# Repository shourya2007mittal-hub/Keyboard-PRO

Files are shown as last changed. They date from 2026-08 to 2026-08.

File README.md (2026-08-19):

# Keyboard-PRO



I have building a 65% layout keyboard and it is  based on Seed Studio Xiao nrf52840 because it has Bluetooth capabilities. the number of available pins on Xiao was less So I used 2 expanders for connection . <br>The keyboard also has a  3.7v battery for the power also it could be charged by the USB-C available on xiao as it has an inbuilt charging IC. <br> The keyboard also has an 0.91 inch OLED Screen . Which will be used to display present time/ and how long are you working for . <br> The  Switches  on the board are also hot swappable. So there is no need to solder the switches and we could easily change it .    <br> The board also include a micro pad of 4x3 layout which could be used as shot-cuts for any apps  and has 3 rotor encoders to control volume/Brightness/ timeline (while editing/ Zoom in-out).

<br> The CAD design is a three layered design in which the Bottom layer holds the keyboard PCB and there is a middle layer holds and give structure to the Switches and stabilizes them . then the top layer close and finished the board. All the three pieces connect to each other in a leg-joint manner. 
<br>

## Features
-  nrf52840 Rp2040
- uses 65% Keyboard Layout 
-  Uses Keyboard Matrix
-  Had a rotor encoder and an 0.91 inch oled screen
-  had a 4x3 layout MicroPad

  | Item | Price | Source |
| :--- | :---: | :--- |
| PCB + Shipping - Coupons | 28.74 | JLCPCB |
| KeyCaps | 15.04 | [Meckeys Link](https://meckeys.com/shop/accessories/keyboard-accessories/keycaps/gengar-anime-keycap-set/) |
| Hot-swap (pack of 10) x7 | 5.20 | [Meckeys Link](https://meckeys.com/shop/accessories/keyboard-accessories/key-switches/kailh-hot-swap-socket/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) |
| Switches (pack of 10) x 8 | 25.20 | [Meckeys Link](https://meckeys.com/shop/accessories/keyboard-accessories/key-switches/hmx-xinhai-switch/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) |
| Stabilizers | 10.76 | [Meckeys Link](https://meckeys.com/shop/accessories/keyboard-accessories/more/glorious-goat-stabilizers/) |
| Meckey shipping | 1.10 | meckeys.com |
| Expander x 2 | 6.22 | [Robu Link](https://robu.in/product/pca9555dwr-texas-instruments-400khz-soic-24-300mil-i-o-expanders-rohs/) |
| XIAO BLE nRF52840 | 12.40 | [Robu Link](https://robu.in/product/seeed-studio-xiao-ble-nrf52840/) |
| 0.91 OLED | 1.93 | [Robu Link](https://robu.in/product/blue-oled-display-module/) |
| Rotor Encoder x 3 | 1.36 | [Robu Link](https://robu.in/product/m274-360-degree-rotary-encoder-module-brick-sensor/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) |
| On-Off switch | 1.12 | [Robu Link](https://robu.in/product/os202011ma0qn1-ck-100ma-dpdt-12v-10000-times-plugin-slide-switches-rohs/) |
| 2M OHM Resistor | 0.13 | [Robu Link](https://robu.in/product/crcw12062m20fkea-vishay-smd-chip-resistor-2-2-mohm-%c2%b1-1-250-mw-1206-3216-metric-thick-film-general-purpose/) |
| 806k resistor | 0.13 | [Robu Link](https://robu.in/product/rc0402fr-07806kl-yageo-smd-chip-resistor-806-kohm-%c2%b1-1-63-mw-0402-1005-metric-thick-film-general-purpose/) |
| Robu shipping | 1.10 | robu.in |
| Solder Paste for SMD components | 2.70 | [Amazon Link](https://www.amazon.in/gp/product/B0GY879KCL/ref=ox_sc_act_title_1?smid=A2TAUOL95KBX1X&psc=1) |
| 1N4148W-T4 diodes (Pack of 15) X 5 *(used Amazon because non-available elsewhere)* | 11.78 | [Amazon Link](https://www.amazon.in/gp/product/B0FZL2D1GG/ref=ox_sc_act_title_2?smid=A28WR0HSDEABON&psc=1) |
| **Total** | **124.91** | |

### Schematic<br><br>



###  PCB Design<br><br>



### 3D Render <br><br>




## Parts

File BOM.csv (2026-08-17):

Item | Price | Source
PCB + Shipping - Coupons | 28.74 | JLCPCB
KeyCaps | 15.04 | https://meckeys.com/shop/accessories/keyboard-accessories/keycaps/gengar-anime-keycap-set/
Hot-swap (pack of 10) x7 | 5.2 | https://meckeys.com/shop/accessories/keyboard-accessories/key-switches/kailh-hot-swap-socket/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
Switches (pack of 10) x 8 | 25.2 | https://meckeys.com/shop/accessories/keyboard-accessories/key-switches/hmx-xinhai-switch/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
Stabilizers | 10.76 | https://meckeys.com/shop/accessories/keyboard-accessories/more/glorious-goat-stabilizers/
Meckey shipping | 1.1 | meckeys.com
Expander x 2 | 6.22 | https://robu.in/product/pca9555dwr-texas-instruments-400khz-soic-24-300mil-i-o-expanders-rohs/
XIAO BLE nRF52840 | 12.4 | https://robu.in/product/seeed-studio-xiao-ble-nrf52840/
0.91 OLED | 1.93 | https://robu.in/product/blue-oled-display-module/
Rotor Encoder x 3 | 1.36 | https://robu.in/product/m274-360-degree-rotary-encoder-module-brick-sensor/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
On-Off switch | 1.12 | https://robu.in/product/os202011ma0qn1-ck-100ma-dpdt-12v-10000-times-plugin-slide-switches-rohs/
2M OHM Resistor | 0.13 | https://robu.in/product/crcw12062m20fkea-vishay-smd-chip-resistor-2-2-mohm-%c2%b1-1-250-mw-1206-3216-metric-thick-film-general-purpose/
806k resistor | 0.13 | https://robu.in/product/rc0402fr-07806kl-yageo-smd-chip-resistor-806-kohm-%c2%b1-1-63-mw-0402-1005-metric-thick-film-general-purpose/
Robu shipping | 1.1 | robu.in
Solder Paste for SND components | 2.7 | https://www.amazon.in/gp/product/B0GY879KCL/ref=ox_sc_act_title_1?smid=A2TAUOL95KBX1X&psc=1
1N4148W-T4 diodes (Pack of 15) X 5 ( used amazon beacuse wasn't avilable anywhere else) | 11.78 | https://www.amazon.in/gp/product/B0FZL2D1GG/ref=ox_sc_act_title_2?smid=A28WR0HSDEABON&psc=1
Total | 124.91

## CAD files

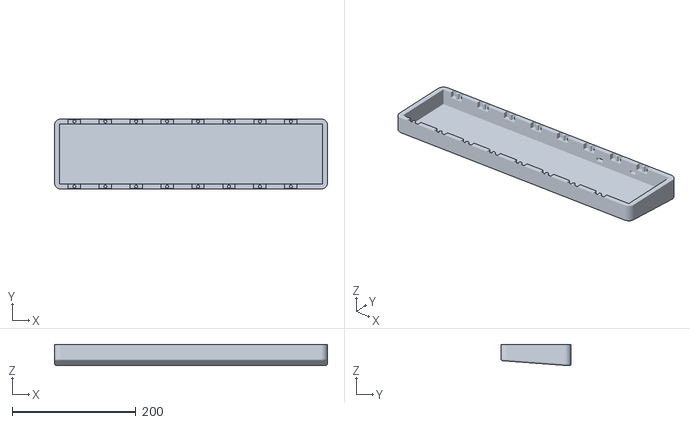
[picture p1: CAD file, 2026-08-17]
Production/CAD/BASE.stl
441.4 x 113.4 x 34.8

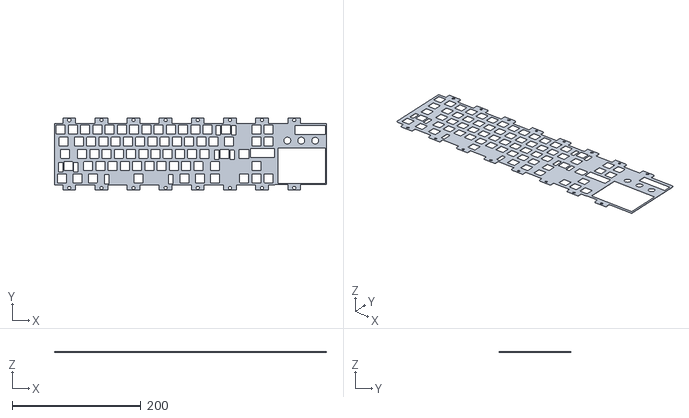
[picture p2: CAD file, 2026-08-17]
Production/CAD/Middle.stl
423.3 x 111.5 x 1.50

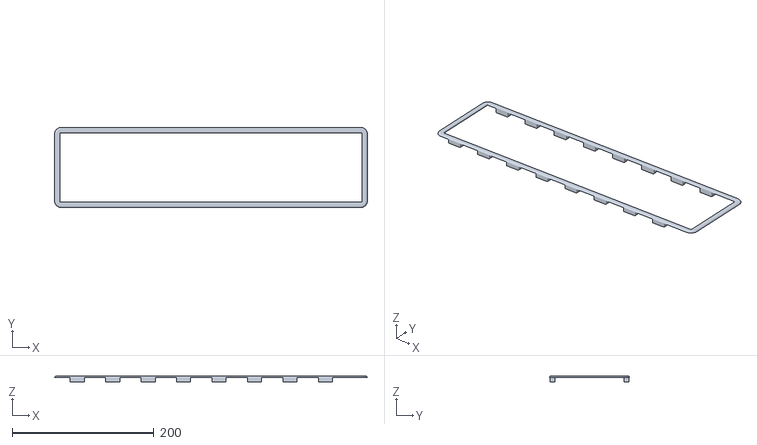
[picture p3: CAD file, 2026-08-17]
Production/CAD/TOP.stl
441.4 x 113.4 x 8.51

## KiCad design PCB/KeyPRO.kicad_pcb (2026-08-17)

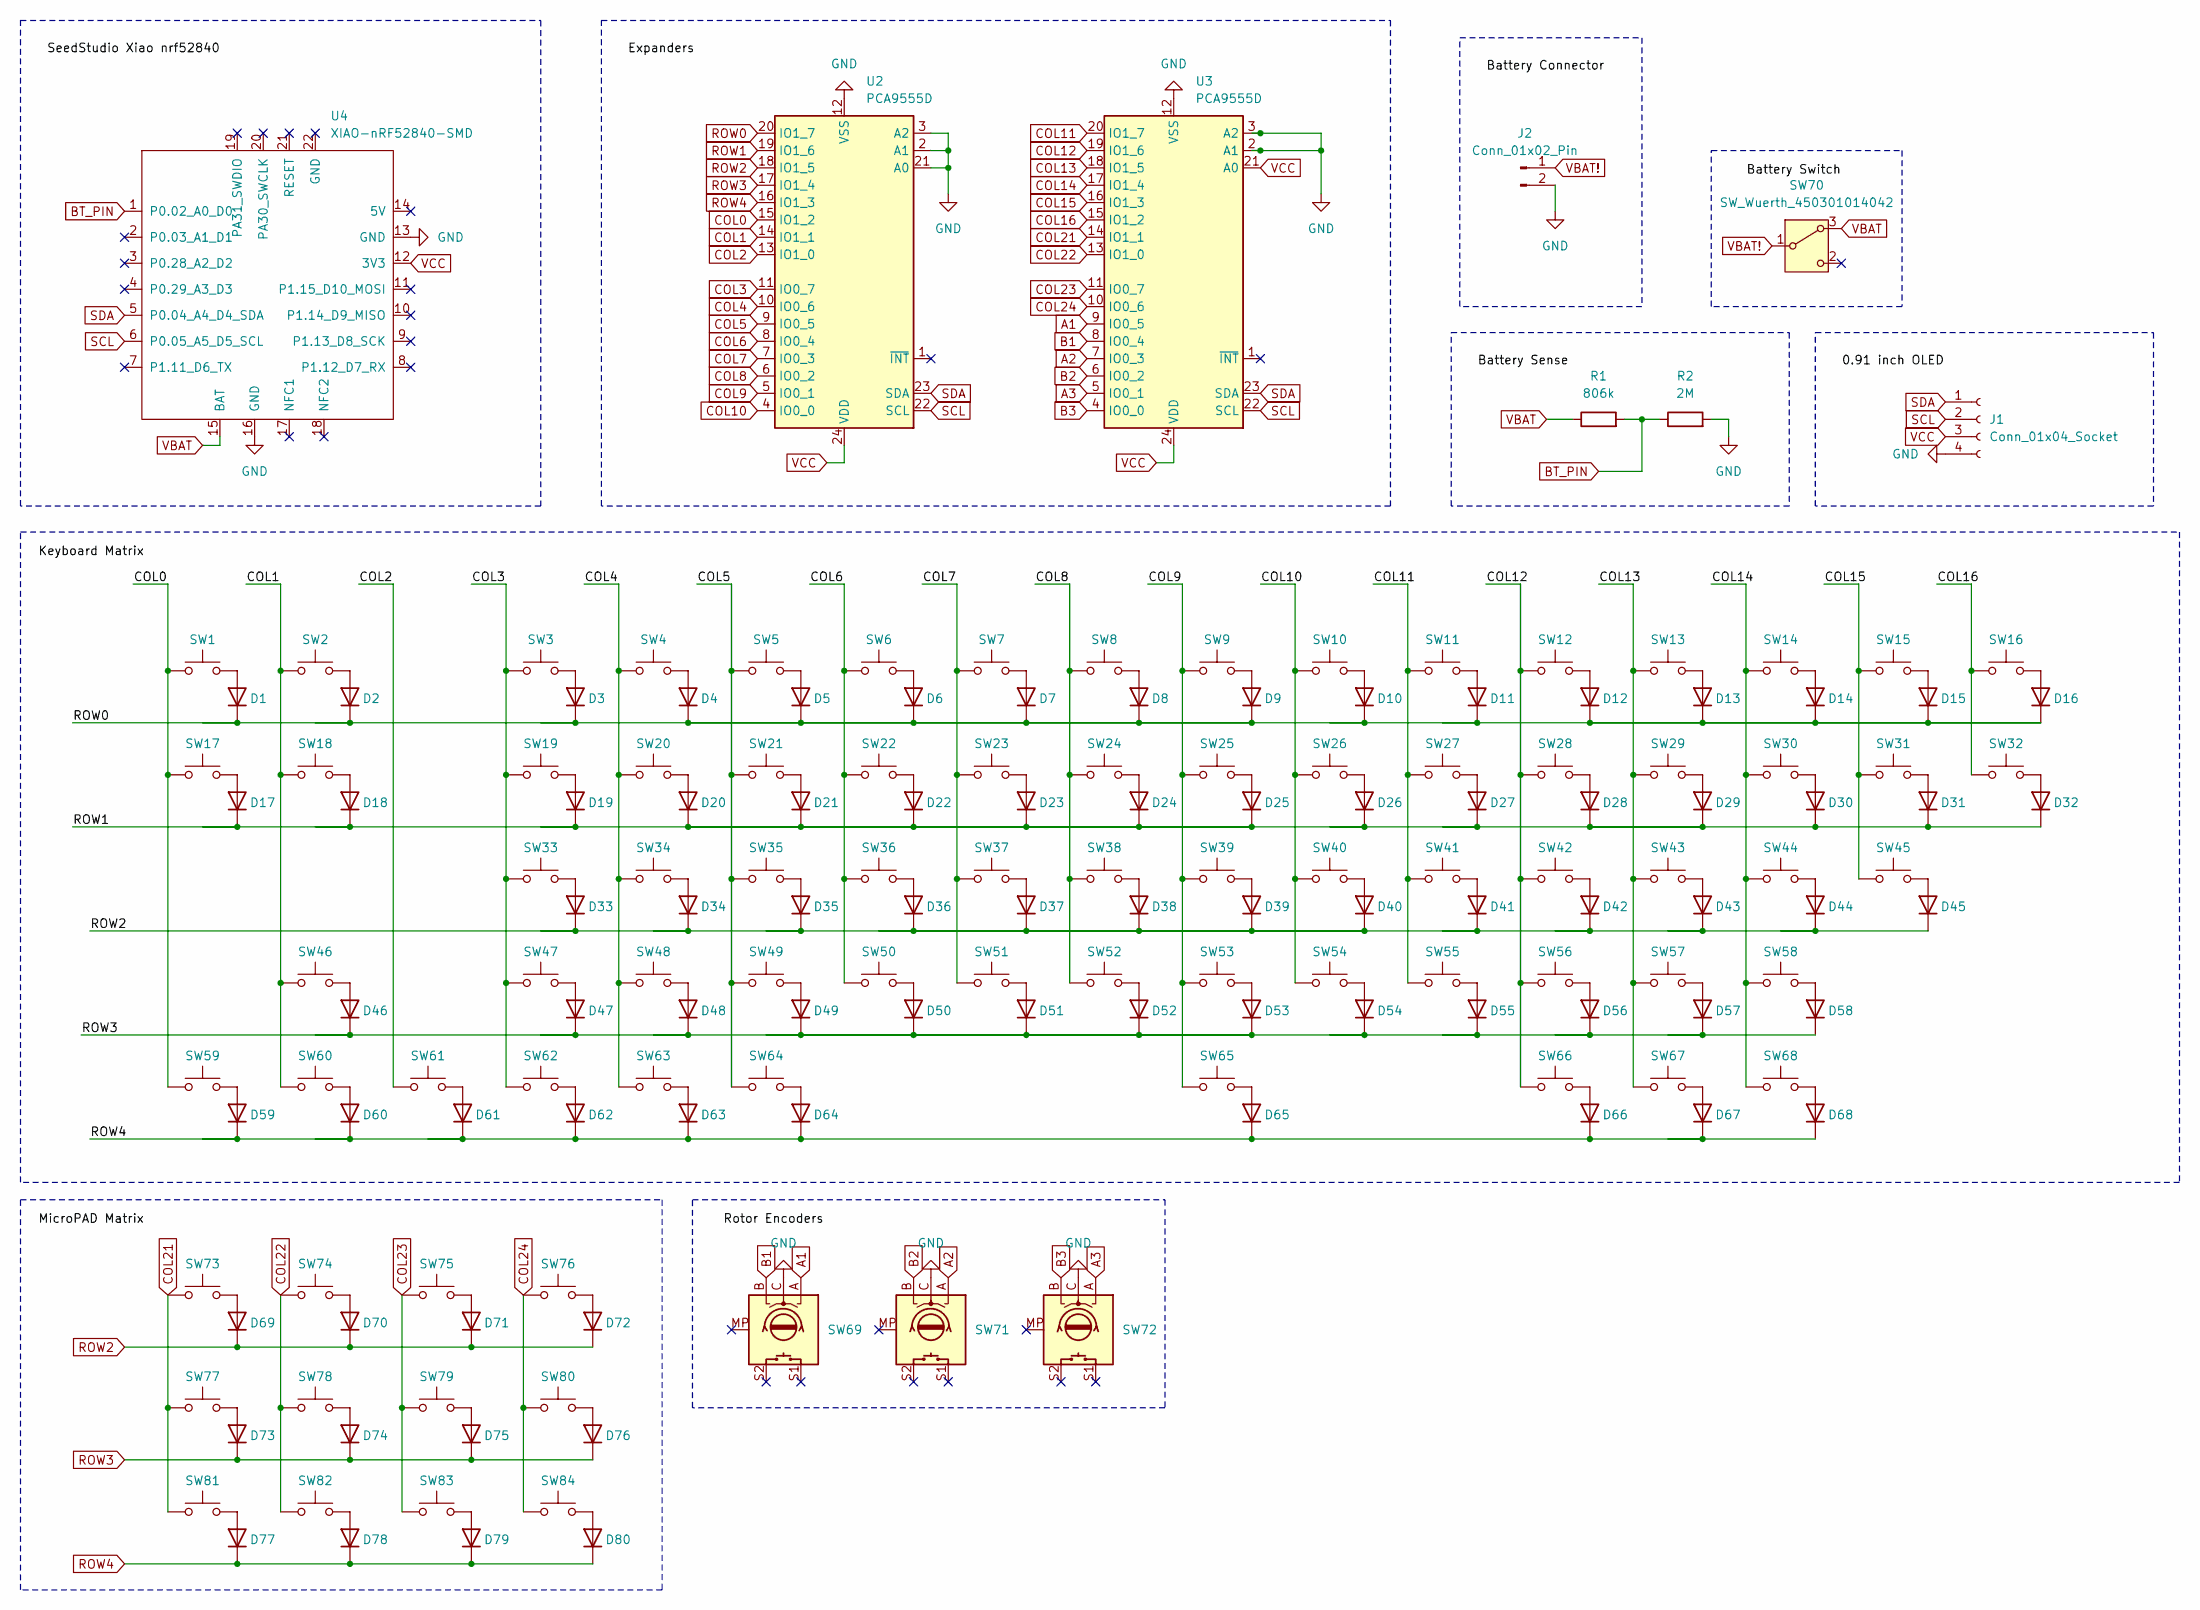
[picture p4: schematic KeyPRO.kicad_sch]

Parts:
D1, D2, D3, D4, D5, D6, D7, D8, D9, D10, D11, D12, D13, D14, D15, D16, D17, D18, D19, D20, D21, D22, D23, D24, D25, D26, D27, D28, D29, D30, D31, D32, D33, D34, D35, D36, D37, D38, D39, D40, D41, D42, D43, D44, D45, D46, D47, D48, D49, D50, D51, D52, D53, D54, D55, D56, D57, D58, D59, D60, D61, D62, D63, D64, D65, D66, D67, D68, D69, D70, D71, D72, D73, D74, D75, D76, D77, D78, D79, D80: D; D_SOD-123
J1: Conn_01x04_Socket; PinHeader_1x04_P2.54mm_Vertical
J2: Conn_01x02_Pin; JST_JWPF_B02B-JWPF-SK-R_1x02_P2.00mm_Vertical
R1: 806k; R_0805_2012Metric
R2: 2M; R_0805_2012Metric
SW1, SW2, SW3, SW4, SW5, SW6, SW7, SW8, SW9, SW10, SW11, SW12, SW13, SW14, SW15, SW16, SW17, SW18, SW19, SW20, SW21, SW22, SW23, SW24, SW25, SW26, SW27, SW28, SW29, SW30, SW31, SW32, SW33, SW34, SW35, SW36, SW37, SW38, SW39, SW40, SW41, SW42, SW43, SW44, SW45, SW46, SW47, SW48, SW49, SW50, SW51, SW52, SW53, SW54, SW55, SW56, SW57, SW58, SW59, SW60, SW61, SW62, SW63, SW64, SW65, SW66, SW67, SW68: SW_Push; SW_MX_HS_CPG151101S11_1u
SW69, SW71, SW72: RotaryEncoder_Switch_MP; RotaryEncoder_Alps_EC11E-Switch_Vertical_H20mm
SW70: SW_Wuerth_450301014042; SW_Slide_SPDT_Straight_CK_OS102011MS2Q
SW73, SW74, SW75, SW76, SW77, SW78, SW79, SW80, SW81, SW82, SW83, SW84: SW_Push; SW_Cherry_MX_1.00u_PCB
U2, U3: PCA9555D; SOIC-24W_7.5x15.4mm_P1.27mm
U4: XIAO-nRF52840-SMD; modified-XIAO-nRF52840-SMD

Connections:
A1: SW69.A, U3.9 (IO0_5)
A2: SW71.A, U3.7 (IO0_3)
A3: SW72.A, U3.5 (IO0_1)
B1: SW69.B, U3.8 (IO0_4)
B2: SW71.B, U3.6 (IO0_2)
B3: SW72.B, U3.4 (IO0_0)
BT_PIN: R1.2, R2.1, U4.1 (P0.02_A0_D0)
COL0: SW1.1, SW17.1, SW59.1, U2.15 (IO1_2)
COL1: SW2.1, SW18.1, SW46.1, SW60.1, U2.14 (IO1_1)
COL2: SW61.1, U2.13 (IO1_0)
COL3: SW3.1, SW19.1, SW33.1, SW47.1, SW62.1, U2.11 (IO0_7)
COL4: SW4.1, SW20.1, SW34.1, SW48.1, SW63.1, U2.10 (IO0_6)
COL5: SW5.1, SW21.1, SW35.1, SW49.1, SW64.1, U2.9 (IO0_5)
COL6: SW6.1, SW22.1, SW36.1, SW50.1, U2.8 (IO0_4)
COL7: SW7.1, SW23.1, SW37.1, SW51.1, U2.7 (IO0_3)
COL8: SW8.1, SW24.1, SW38.1, SW52.1, U2.6 (IO0_2)
COL9: SW9.1, SW25.1, SW39.1, SW53.1, SW65.1, U2.5 (IO0_1)
COL10: SW10.1, SW26.1, SW40.1, SW54.1, U2.4 (IO0_0)
COL11: SW11.1, SW27.1, SW41.1, SW55.1, U3.20 (IO1_7)
COL12: SW12.1, SW28.1, SW42.1, SW56.1, SW66.1, U3.19 (IO1_6)
COL13: SW13.1, SW29.1, SW43.1, SW57.1, SW67.1, U3.18 (IO1_5)
COL14: SW14.1, SW30.1, SW44.1, SW58.1, SW68.1, U3.17 (IO1_4)
COL15: SW15.1, SW31.1, SW45.1, U3.16 (IO1_3)
COL16: SW16.1, SW32.1, U3.15 (IO1_2)
COL21: SW73.1, SW77.1, SW81.1, U3.14 (IO1_1)
COL22: SW74.1, SW78.1, SW82.1, U3.13 (IO1_0)
COL23: SW75.1, SW79.1, SW83.1, U3.11 (IO0_7)
COL24: SW76.1, SW80.1, SW84.1, U3.10 (IO0_6)
GND: J1.4, J2.2, R2.2, SW69.C, SW71.C, SW72.C, U2.2 (A1), U2.3 (A2), U2.12 (VSS), U2.21 (A0), U3.2 (A1), U3.3 (A2), U3.12 (VSS), U4.13 (GND), U4.16 (GND)
unnamed: D1.2 (A), SW1.2
unnamed: D2.2 (A), SW2.2
unnamed: D3.2 (A), SW3.2
unnamed: D4.2 (A), SW4.2
unnamed: D5.2 (A), SW5.2
unnamed: D6.2 (A), SW6.2
unnamed: D7.2 (A), SW7.2
unnamed: D8.2 (A), SW8.2
unnamed: D9.2 (A), SW9.2
unnamed: D10.2 (A), SW10.2
unnamed: D11.2 (A), SW11.2
unnamed: D12.2 (A), SW12.2
unnamed: D13.2 (A), SW13.2
unnamed: D14.2 (A), SW14.2
unnamed: D15.2 (A), SW15.2
unnamed: D16.2 (A), SW16.2
unnamed: D17.2 (A), SW17.2
unnamed: D18.2 (A), SW18.2
unnamed: D19.2 (A), SW19.2
unnamed: D20.2 (A), SW20.2
unnamed: D21.2 (A), SW21.2
unnamed: D22.2 (A), SW22.2
unnamed: D23.2 (A), SW23.2
unnamed: D24.2 (A), SW24.2
unnamed: D25.2 (A), SW25.2
unnamed: D26.2 (A), SW26.2
unnamed: D27.2 (A), SW27.2
unnamed: D28.2 (A), SW28.2
unnamed: D29.2 (A), SW29.2
unnamed: D30.2 (A), SW30.2
unnamed: D31.2 (A), SW31.2
unnamed: D32.2 (A), SW32.2
unnamed: D33.2 (A), SW33.2
unnamed: D34.2 (A), SW34.2
unnamed: D35.2 (A), SW35.2
unnamed: D36.2 (A), SW36.2
unnamed: D37.2 (A), SW37.2
unnamed: D38.2 (A), SW38.2
unnamed: D39.2 (A), SW39.2
unnamed: D40.2 (A), SW40.2
unnamed: D41.2 (A), SW41.2
unnamed: D42.2 (A), SW42.2
unnamed: D43.2 (A), SW43.2
unnamed: D44.2 (A), SW44.2
unnamed: D45.2 (A), SW45.2
unnamed: D46.2 (A), SW46.2
unnamed: D47.2 (A), SW47.2
unnamed: D48.2 (A), SW48.2
unnamed: D49.2 (A), SW49.2
unnamed: D50.2 (A), SW50.2
unnamed: D51.2 (A), SW51.2
unnamed: D52.2 (A), SW52.2
unnamed: D53.2 (A), SW53.2
unnamed: D54.2 (A), SW54.2
unnamed: D55.2 (A), SW55.2
unnamed: D56.2 (A), SW56.2
unnamed: D57.2 (A), SW57.2
unnamed: D58.2 (A), SW58.2
unnamed: D59.2 (A), SW59.2
unnamed: D60.2 (A), SW60.2
unnamed: D61.2 (A), SW61.2
unnamed: D62.2 (A), SW62.2
unnamed: D63.2 (A), SW63.2
unnamed: D64.2 (A), SW64.2
unnamed: D65.2 (A), SW65.2
unnamed: D66.2 (A), SW66.2
unnamed: D67.2 (A), SW67.2
unnamed: D68.2 (A), SW68.2
unnamed: D69.2 (A), SW73.2
unnamed: D70.2 (A), SW74.2
unnamed: D71.2 (A), SW75.2
unnamed: D72.2 (A), SW76.2
unnamed: D73.2 (A), SW77.2
unnamed: D74.2 (A), SW78.2
unnamed: D75.2 (A), SW79.2
unnamed: D76.2 (A), SW80.2
unnamed: D77.2 (A), SW81.2
unnamed: D78.2 (A), SW82.2
unnamed: D79.2 (A), SW83.2
unnamed: D80.2 (A), SW84.2
ROW0: D1.1 (K), D2.1 (K), D3.1 (K), D4.1 (K), D5.1 (K), D6.1 (K), D7.1 (K), D8.1 (K), D9.1 (K), D10.1 (K), D11.1 (K), D12.1 (K), D13.1 (K), D14.1 (K), D15.1 (K), D16.1 (K), U2.20 (IO1_7)
ROW1: D17.1 (K), D18.1 (K), D19.1 (K), D20.1 (K), D21.1 (K), D22.1 (K), D23.1 (K), D24.1 (K), D25.1 (K), D26.1 (K), D27.1 (K), D28.1 (K), D29.1 (K), D30.1 (K), D31.1 (K), D32.1 (K), U2.19 (IO1_6)
ROW2: D33.1 (K), D34.1 (K), D35.1 (K), D36.1 (K), D37.1 (K), D38.1 (K), D39.1 (K), D40.1 (K), D41.1 (K), D42.1 (K), D43.1 (K), D44.1 (K), D45.1 (K), D69.1 (K), D70.1 (K), D71.1 (K), D72.1 (K), U2.18 (IO1_5)
ROW3: D46.1 (K), D47.1 (K), D48.1 (K), D49.1 (K), D50.1 (K), D51.1 (K), D52.1 (K), D53.1 (K), D54.1 (K), D55.1 (K), D56.1 (K), D57.1 (K), D58.1 (K), D73.1 (K), D74.1 (K), D75.1 (K), D76.1 (K), U2.17 (IO1_4)
ROW4: D59.1 (K), D60.1 (K), D61.1 (K), D62.1 (K), D63.1 (K), D64.1 (K), D65.1 (K), D66.1 (K), D67.1 (K), D68.1 (K), D77.1 (K), D78.1 (K), D79.1 (K), D80.1 (K), U2.16 (IO1_3)
SCL: J1.2, U2.22 (SCL), U3.22 (SCL), U4.6 (P0.05_A5_D5_SCL)
SDA: J1.1, U2.23 (SDA), U3.23 (SDA), U4.5 (P0.04_A4_D4_SDA)
VBAT: R1.1, SW70.3 (A), U4.15 (BAT)
VBAT!: J2.1, SW70.1 (B)
VCC: J1.3, U2.24 (VDD), U3.21 (A0), U3.24 (VDD), U4.12 (3V3)

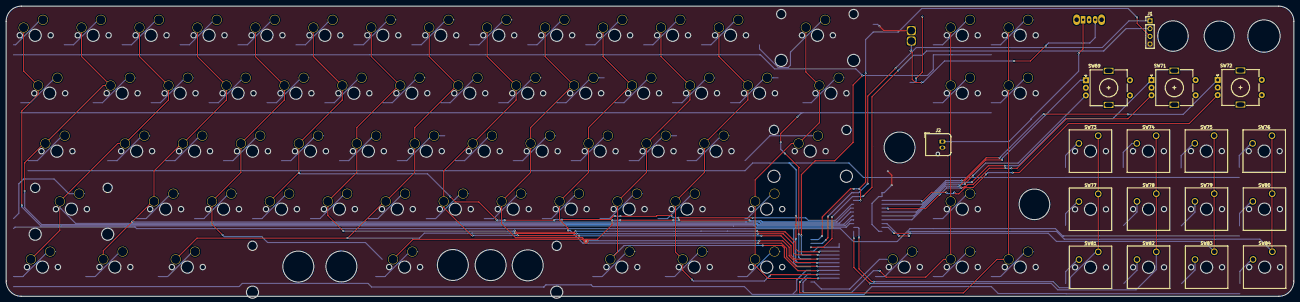
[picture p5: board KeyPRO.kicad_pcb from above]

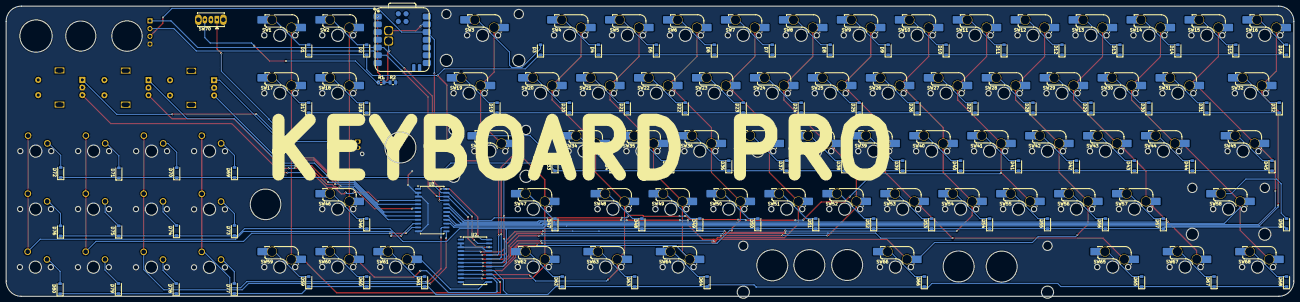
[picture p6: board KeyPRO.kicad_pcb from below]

Board: 2 copper layers, 423.4 x 95.4 mm, 175 parts (154 on the bottom side), 119 nets.

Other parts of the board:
S1: STAB_MX_2u
S2, S3: STAB_MX_2.25u
S4: STAB_MX_6.25u

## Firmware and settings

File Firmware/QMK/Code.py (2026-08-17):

import board
from kmk.kmk_keyboard import KMKKeyboard
from kmk.keys import KC
from kmk.scanners import DiodeOrientation
from kmk.modules.layers import Layers

keyboard = KMKKeyboard()
keyboard.modules.append(Layers())

# ===== MATRIX PINS (MATCH YOUR SCHEMATIC) =====
keyboard.row_pins = (
    board.GP26,
    board.GP27,
    board.GP28,
    board.GP29,
    board.GP6,
)

keyboard.col_pins = (
    board.GP0,
    board.GP1,
    board.GP2,
    board.GP3,
    board.GP4,
    board.GP5,
    board.GP7,
    board.GP8,
    board.GP9,
    board.GP10,
    board.GP11,
    board.GP12,
    board.GP13,
    board.GP14,
)

keyboard.diode_orientation = DiodeOrientation.COLUMNS

# ===== KEYMAP =====
keyboard.keymap = [
    [
        KC.ESC, KC.N1, KC.N2, KC.N3, KC.N4, KC.N5, KC.N6, KC.N7, KC.N8, KC.N9, KC.N0, KC.MINS, KC.EQL, KC.BSPC,
        KC.TAB, KC.Q,  KC.W,  KC.E,  KC.R,  KC.T,  KC.Y,  KC.U,  KC.I,  KC.O,  KC.P,  KC.LBRC, KC.RBRC, KC.BSLS,
        KC.CAPS,KC.A,  KC.S,  KC.D,  KC.F,  KC.G,  KC.H,  KC.J,  KC.K,  KC.L,  KC.SCLN, KC.QUOT, KC.ENT,
        KC.LSFT,KC.Z,  KC.X,  KC.C,  KC.V,  KC.B,  KC.N,  KC.M,  KC.COMM,KC.DOT, KC.SLSH, KC.RSFT,
        KC.LCTL,KC.LGUI,KC.LALT,KC.SPC,KC.RALT,KC.RGUI,KC.MO(1),KC.RCTL
    ],
    [
        KC.GRV, KC.F1, KC.F2, KC.F3, KC.F4, KC.F5, KC.F6, KC.F7, KC.F8, KC.F9, KC.F10, KC.F11, KC.F12, KC.DEL,
        KC.NO,  KC.NO, KC.UP, KC.NO, KC.NO, KC.NO, KC.NO, KC.NO, KC.NO, KC.NO, KC.NO, KC.NO, KC.NO, KC.NO,
        KC.NO, KC.LEFT,KC.DOWN,KC.RIGHT,KC.NO,KC.NO,KC.NO,KC.NO,KC.NO,KC.NO,KC.NO,KC.NO,KC.NO,
        KC.NO, KC.NO, KC.NO, KC.NO, KC.NO, KC.NO, KC.NO, KC.NO, KC.NO, KC.NO, KC.NO, KC.NO,
        KC.NO, KC.NO, KC.NO, KC.NO, KC.NO, KC.NO, KC.NO, KC.NO
    ]
]

if __name__ == '__main__':
    keyboard.go()
